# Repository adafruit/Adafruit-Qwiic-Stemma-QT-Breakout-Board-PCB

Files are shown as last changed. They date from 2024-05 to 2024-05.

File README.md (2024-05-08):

## Adafruit Qwiic / Stemma QT Breakout Board PCB

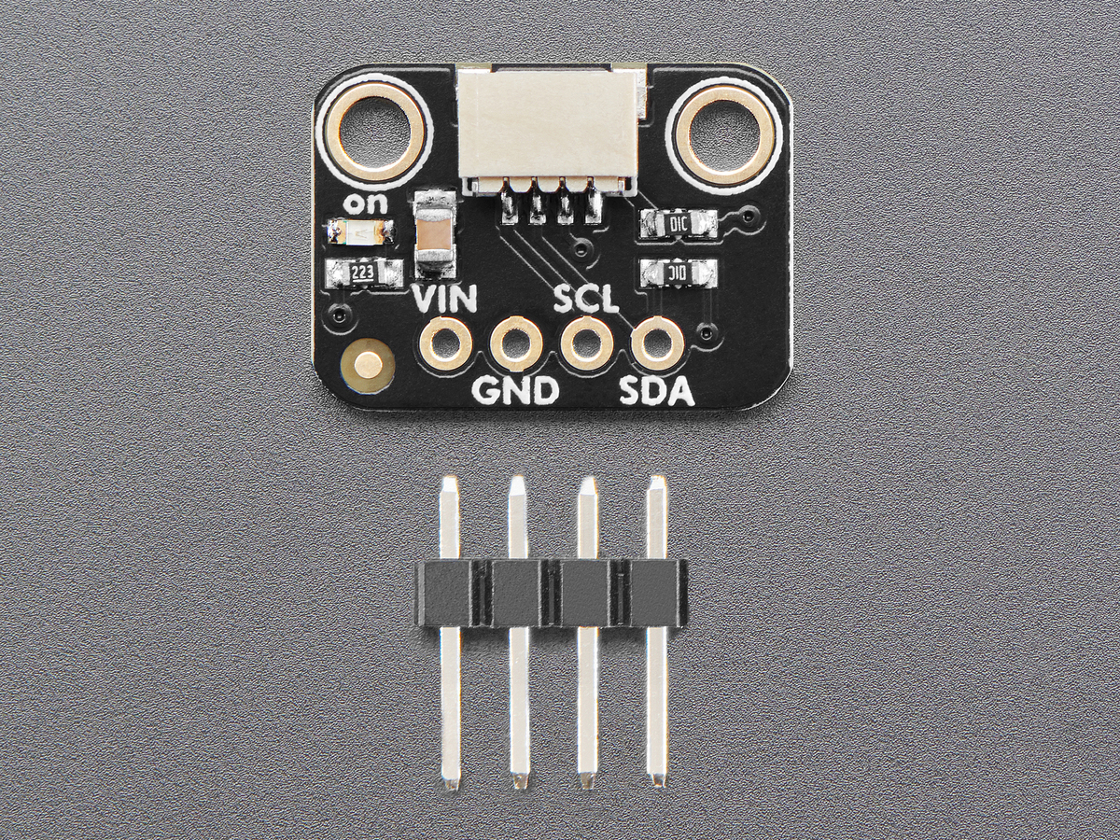
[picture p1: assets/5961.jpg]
<a href="http://www.adafruit.com/products/5961"><br/>
Click here to purchase one from the Adafruit shop</a>

PCB files for the Adafruit Qwiic / Stemma QT Breakout Board. 

Format is EagleCAD schematic and board layout
* https://www.adafruit.com/product/5961

### Description

We got a request from a customer for a board that makes connecting between a breadboard and Stemma QT or Qwiic components easy, and here's what we whipped up!

The Adafruit Qwiic / Stemma QT Breakout Board is pretty simple: on one end is a JST SH-compatible connector, that will let you plug-and-play to the Qwiic or Stemma QT universe. On the other side is four 0.1" spaced pads where you can solder header or wires as you wish. In between are two 10K pullup resistors from the two I2C SDA/SCL lines to the positive power pin, plus a green ON LED so you know when the power pin and ground are properly wired.

And that's it! Simple but effective. You can use it both with 'I2C controllers' like a Feather, Metro, QT Py, or with 'I2C devices' like sensors, OLEDs or GPIO expanders. Since the lines just pass through, you can use it with 3 or 5V power and logic. The LED and pull-up resistors can be deactivated by cutting some small traces on the back of the PCB, if they are not needed.

### License

Adafruit invests time and resources providing this open source design, please support Adafruit and open-source hardware by purchasing products from [Adafruit](https://www.adafruit.com)!

Designed by Limor Fried/Ladyada for Adafruit Industries.

Creative Commons Attribution/Share-Alike, all text above must be included in any redistribution. 
See license.txt for additional details.

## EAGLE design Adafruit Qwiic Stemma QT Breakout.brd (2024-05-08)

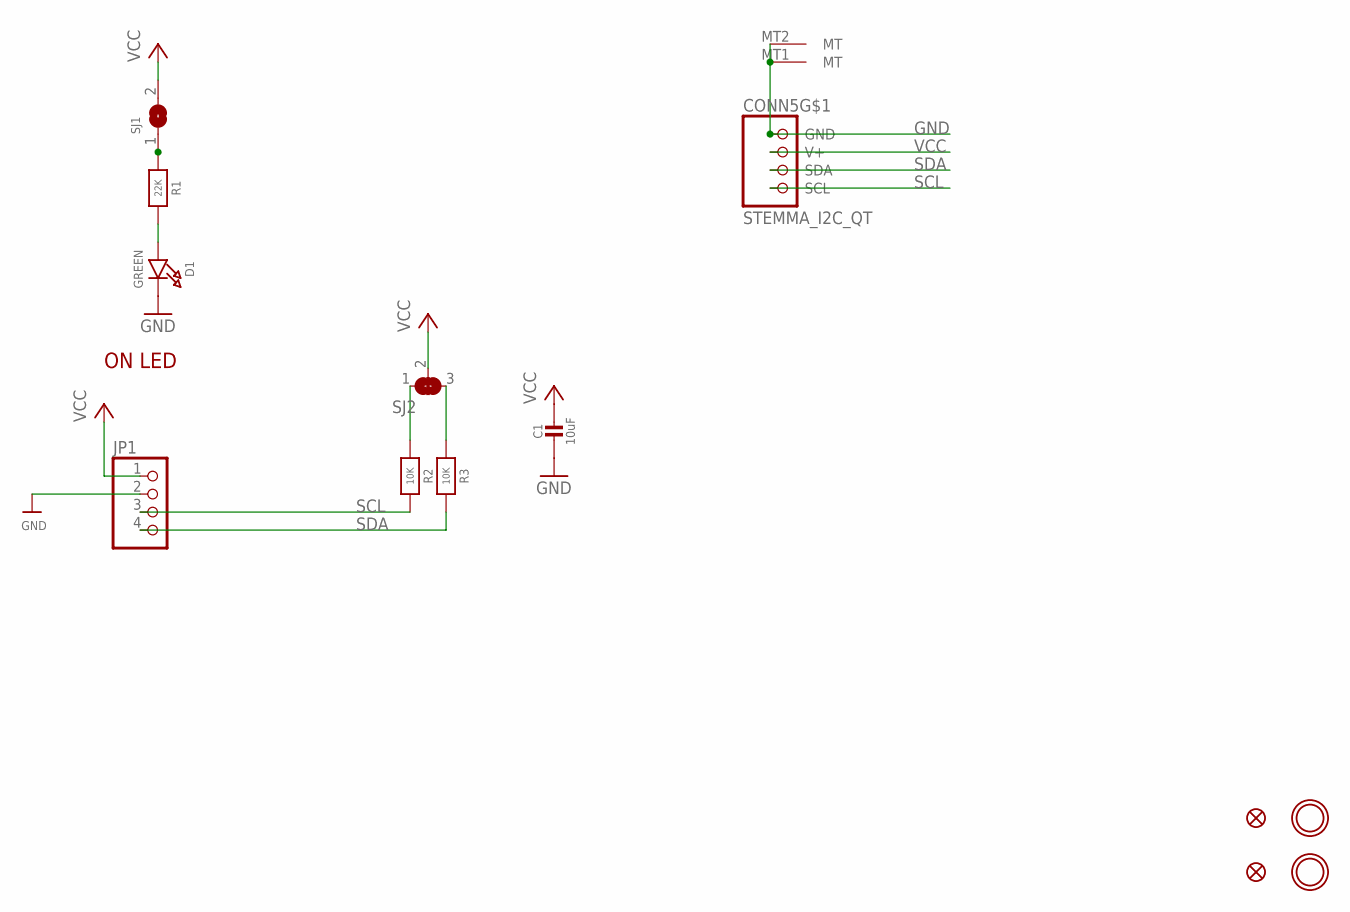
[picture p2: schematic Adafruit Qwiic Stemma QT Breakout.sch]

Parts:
C1: 10uF; 0805-NO
CONN5: STEMMA_I2C_QT; JST_SH4
D1: GREEN; CHIPLED_0603_NOOUTLINE
FID3, FID4: FIDUCIAL_1MM
JP1: HEADER-1X476MIL; 1X04_ROUND_76
R1: 22K; 0603-NO
R2, R3: 10K; 0603-NO
SJ1: SOLDERJUMPERCLOSED; SOLDERJUMPER_CLOSEDWIRE
SJ2: SOLDERJUMPER_2WAY; SOLDERJUMPER_2WAY_OPEN_NOPASTE
U$1, U$17: MOUNTINGHOLE2.5; MOUNTINGHOLE_2.5_PLATED

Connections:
GND: C1.2, CONN5.1 (GND), CONN5.MT1 (MT), CONN5.MT2 (MT), D1.C, JP1.2
unnamed: D1.A, R1.2
unnamed: R1.1, SJ1.1
unnamed: R2.1, SJ2.1
unnamed: R3.1, SJ2.3
SCL: CONN5.4 (SCL), JP1.3, R2.2
SDA: CONN5.3 (SDA), JP1.4, R3.2
VCC: C1.1, CONN5.2 (V+), JP1.1, SJ1.2, SJ2.2

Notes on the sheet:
ON LED

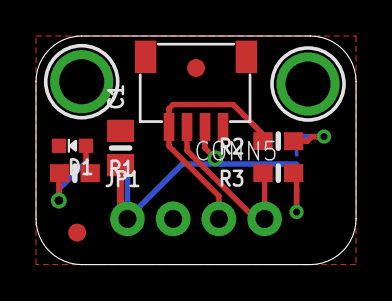
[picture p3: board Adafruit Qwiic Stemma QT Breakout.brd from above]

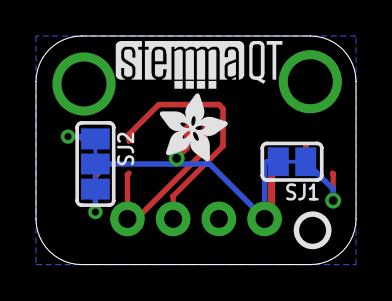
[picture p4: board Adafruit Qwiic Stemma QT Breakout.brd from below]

Board: 2 copper layers, 17.8 x 12.7 mm, 23 parts (7 on the bottom side), 8 nets.

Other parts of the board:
PLABEL0: PLABEL0
PLABEL1: PLABEL1
PLABEL2: PLABEL2
PLABEL3: PLABEL3
PLABEL4: PLABEL4
PLABEL5: PLABEL5
PLABEL6: PLABEL6
U$2: ADAFRUIT_3.5MM
U$25: PCBFEAT-REV-040
U$31: STEMMAQT

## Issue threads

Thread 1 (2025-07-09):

0.1" Pin Order Doesn't Follow STEMMA QT Technical Specs

cfunseth, 2025-07-09:
I'm not sure if this is the correct place to document this or not, but I was wondering if it would be possible to revise this design to have the 0.1" pin header follow the STEMMA QT pin order per the Adafruit technical specification: https://learn.adafruit.com/introducing-adafruit-stemma-qt/technical-specs

I have several I2C peripheral boards I've designed to use this pin order, and this breakout would be a fantastic through-hole adapter to allow use of pre-made STEMMA QT cables rather than having to solder wires or surface mount connectors to the peripheral. This board would also save having to add the pull-up resistors and a LED indicator to new peripherals, which would be a great bonus.

If the board can't be revised since it's already released and I assume many have already been sold, would there be any appetite to releasing a variant that does follow the standard pin order?

Thanks!

ladyada, 2025-07-13:
hi, we dont understand youre question. the cable is the standard order. the gpio pins are also in our preferred (altho not required) order. this board is released and stocked.

cfunseth, 2025-07-14:
Thank you for responding! You answered my question: whether there was a standard pin layout for STEMMA QT I should be following.

I'll plan to use this board's pin order on future board designs, thanks!

Closed 2025-07-13.

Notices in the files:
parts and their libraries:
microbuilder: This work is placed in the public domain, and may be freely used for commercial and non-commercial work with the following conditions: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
